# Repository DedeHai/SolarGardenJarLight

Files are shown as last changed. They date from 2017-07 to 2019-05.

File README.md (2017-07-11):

# Solar Garden Jar Light
A solar powered LED light controlled by an Arduino. It is designed to fit inside most glass jars lighting up your garden or back yard in beatuiful colors. 
The Arduino is connected to an accelerometer to switch the light on and off and to change the color by tilting it. It was designed with easy assembly in mind to be sold as a DIY kit at [Fablab Winti](www.fablabwinti.ch). The voltage regulator as well as the power LED are removed from the Arduino to make it low power consumption consuming only 120µA on average when switched off, making the 500mAh battery last up to half a year when kept in the dark. The solar cell voltage is used to detect low light conditions at dawn and the light does automatically switch on for a few hours if the battery is fully charged. The threshold levels can be adjusted easily in the software.

More information available at https://bashtelorofscience.wordpress.com/ 

License:
Software source code is GNU GPL V3 licensed
Hardware under Creative Commons 4.0 license: CC-BY-NC-SA



# Software
The PCB was designed in **eagle** version 7.5.0. The firmware project was created using **Arduino IDE**.

# Fotos
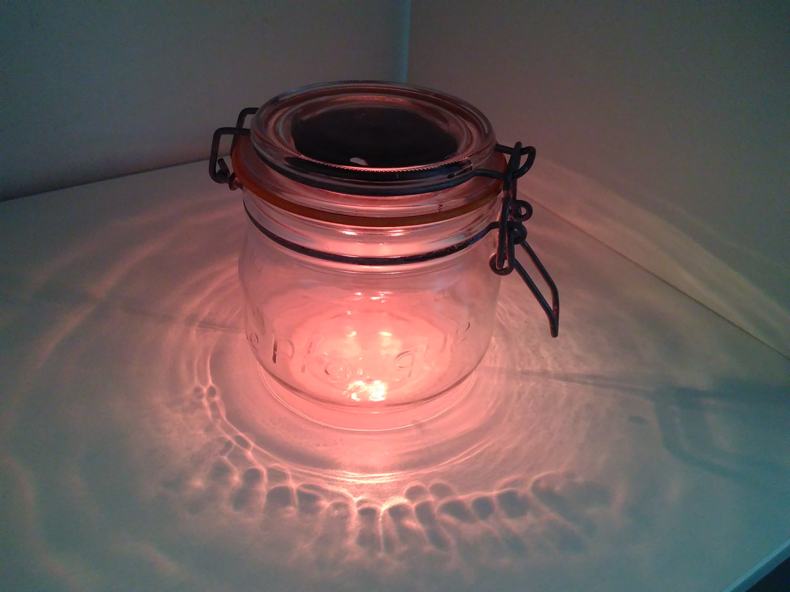
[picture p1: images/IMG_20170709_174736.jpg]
Finished Jar
 
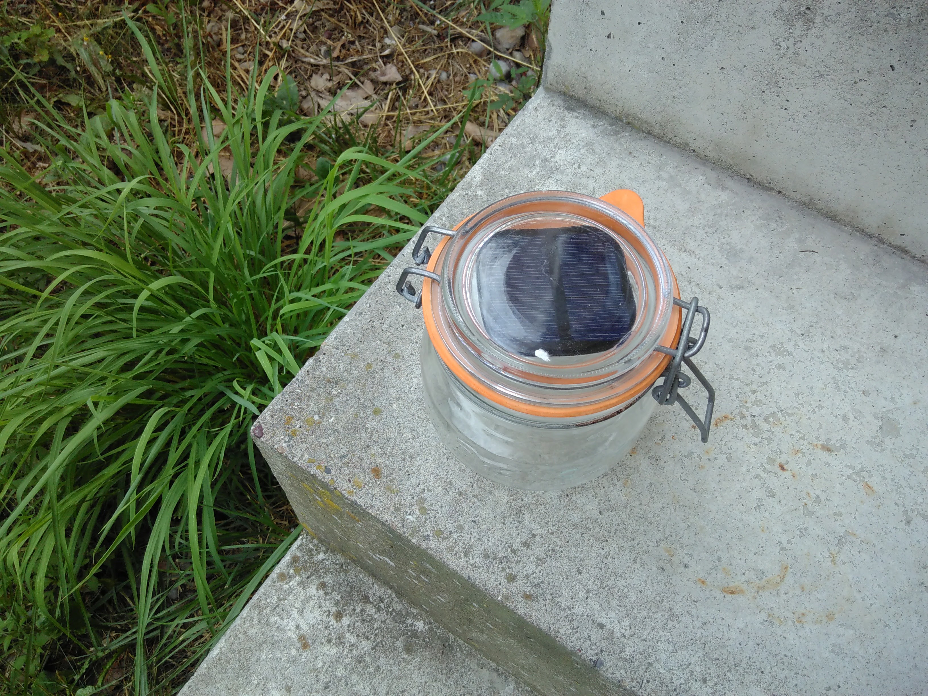
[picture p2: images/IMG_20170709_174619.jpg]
Outside
 
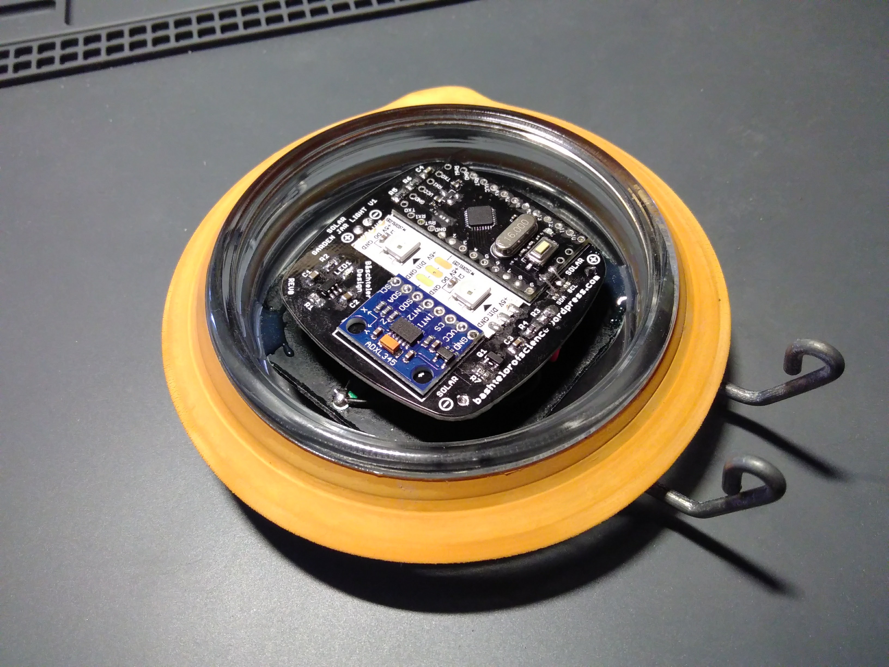
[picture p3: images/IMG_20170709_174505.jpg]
Assemblded Lid
 
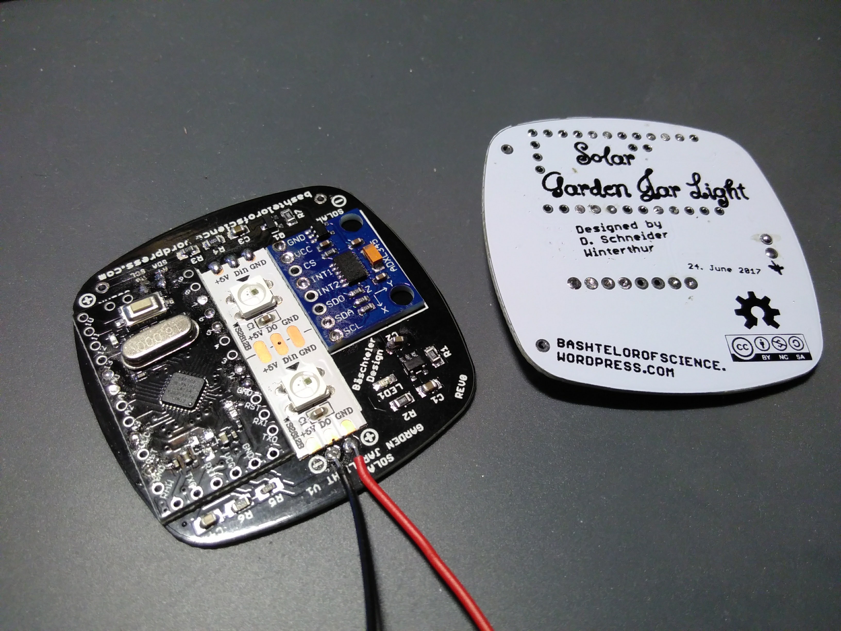
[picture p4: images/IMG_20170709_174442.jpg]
Assemblded PCB


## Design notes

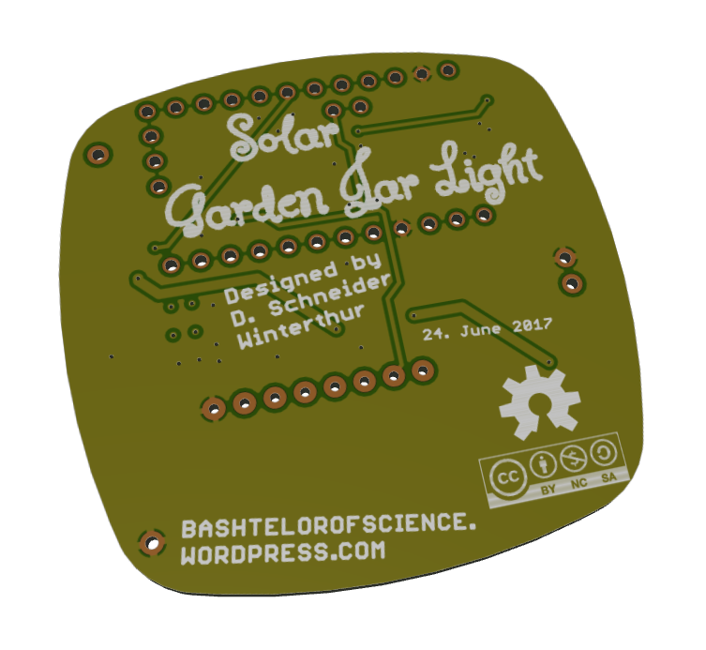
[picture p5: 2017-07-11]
Hardware/PCB_bottomview.PNG

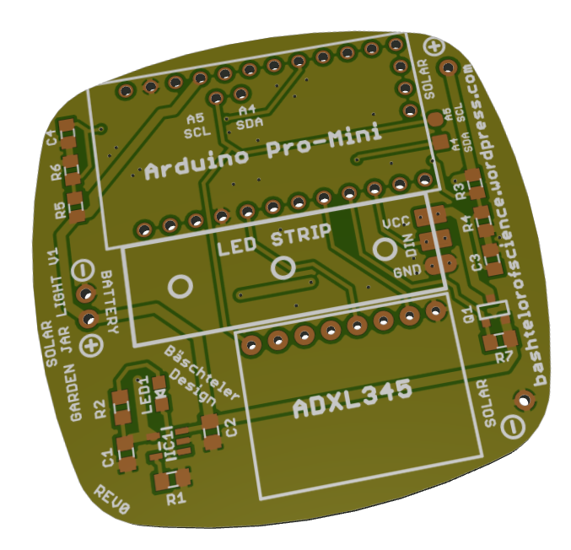
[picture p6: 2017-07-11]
Hardware/PCB_topview.PNG

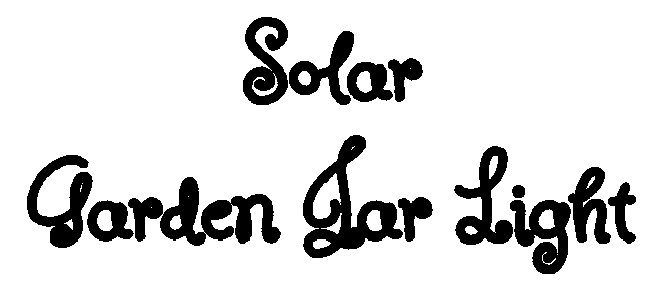
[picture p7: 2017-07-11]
Hardware/SolarGardenJarLight.bmp

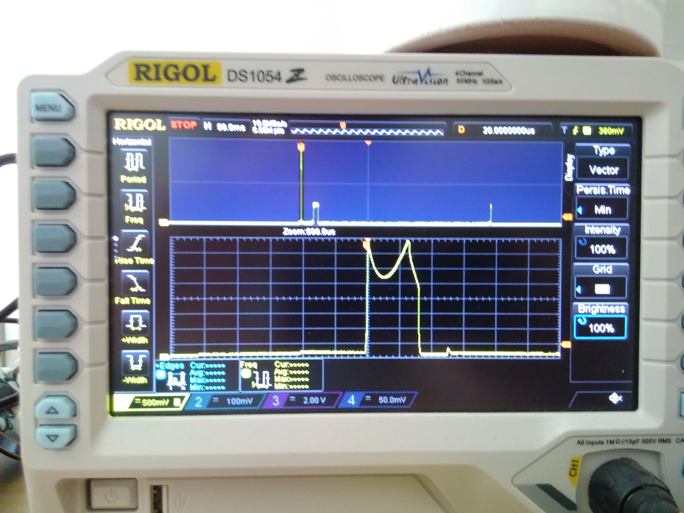
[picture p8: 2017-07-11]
images/initial spike 100x.jpg

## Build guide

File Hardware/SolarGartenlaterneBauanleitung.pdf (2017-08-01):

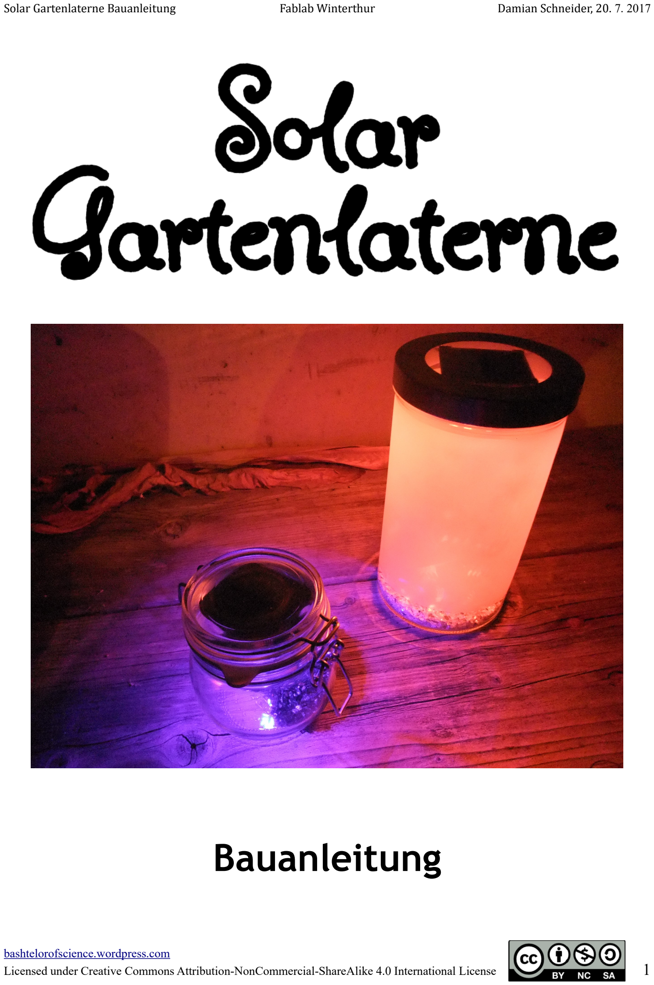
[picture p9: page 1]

Solar Gartenlaterne Bauanleitung | Fablab Winterthur | Damian Schneider, 20. 7. 2017

# Bauanleitung

bashtelorofscience.wordpress.com
Licensed under Creative Commons Attribution-NonCommercial-ShareAlike 4.0 International License | 1

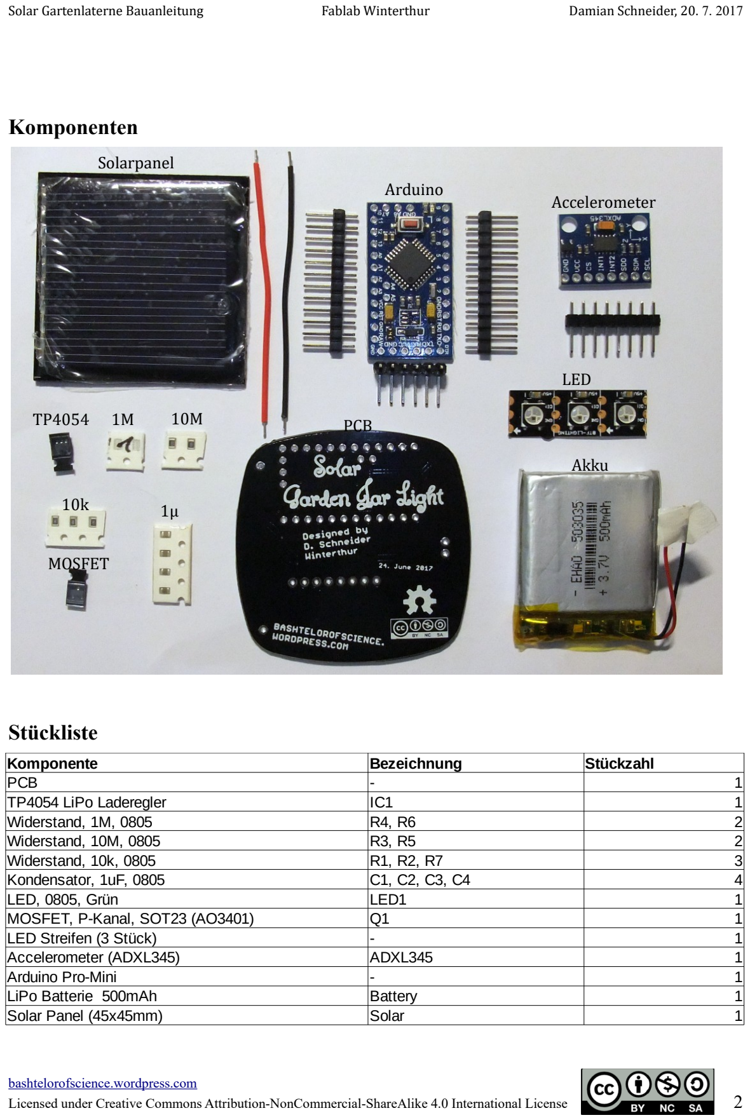
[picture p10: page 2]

Komponenten

Stückliste

bashtelorofscience.wordpress.com
Licensed under Creative Commons Attribution-NonCommercial-ShareAlike 4.0 International License | 2
1M | PCB

Solarpanel

MOSFET

Akku

10k | 1µ

TP4054

Arduino

LED

Accelerometer

10M

Komponente | Bezeichnung | Stückzahl
PCB | - | 1
TP4054 LiPo Laderegler | IC1 | 1
Widerstand, 1M, 0805 | R4, R6 | 2
Widerstand, 10M, 0805 | R3, R5 | 2
Widerstand, 10k, 0805 | R1, R2, R7 | 3
Kondensator, 1uF, 0805 | C1, C2, C3, C4 | 4
LED, 0805, Grün | LED1 | 1
MOSFET, P-Kanal, SOT23 (AO3401) | Q1 | 1
LED Streifen (3 Stück) | - | 1
Accelerometer (ADXL345) | ADXL345 | 1
Arduino Pro-Mini | - | 1
LiPo Batterie 500mAh | Battery | 1
Solar Panel (45x45mm) | Solar | 1

Bestückungsplan

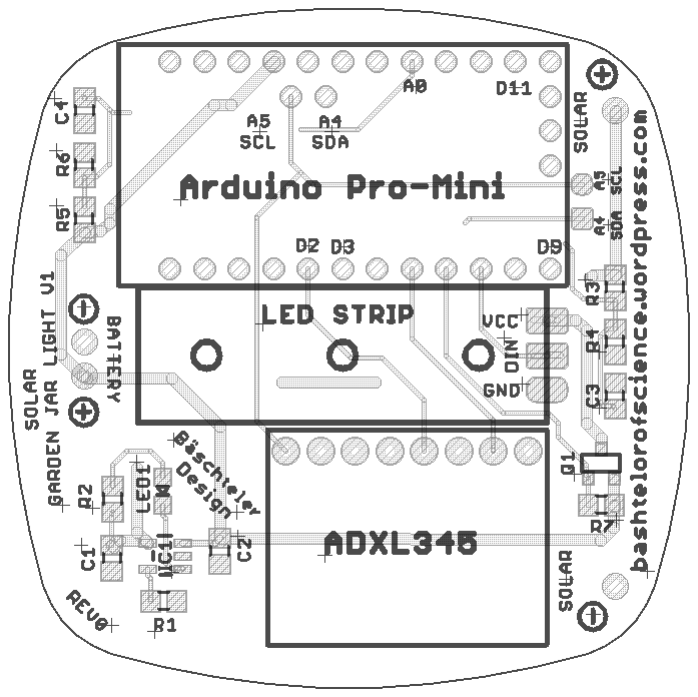
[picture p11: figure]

SMD Komponenten
Die SMD Komponenten gemäss obigem Bestückungsplane löten (Stückliste beachten). Wichtig ist dabei die Widerstände R3, R4, R5 und R6 nicht zu vertauschen. R3 und R5 sind 10M und R4 und R6 sind 1M. Beim IC1 ist besonders auf Kurzschlüsse zu achten und bei LED1 auf die korrekte Polarität.
Arduino
Das Arduino Pro-Mini ist bereits modifiziert: die Power-LED sowie der Linearregler wurde entfernt um den Stromverbrauch auf ein Minimum zu reduzieren.
Zuerst werden die Stiftleisten ins Arduino-Board eingelötet (kurze Stiftseite zum Arduino). Dabei die extra Pins A4 und A5 nicht vergessen (bei den blauen Boards, siehe Anmerkung unten)! Am einfachsten ist es, die Stiftleisten erst ins PCB der Solar-Gartenlaterne einzusetzen, das Arduino

bashtelorofscience.wordpress.com
Licensed under Creative Commons Attribution-NonCommercial-ShareAlike 4.0 International License | 3

daraufzusetzen und dann anzulöten. Damit sind die Pins sicher gut ausgerichtet (siehe Foto). Achtung: das Arduino nicht verkehrt herum einlöten, Ausrichtung siehe Bestückungsplan (Pins D2, D3, D9, D11, A0 beachten).

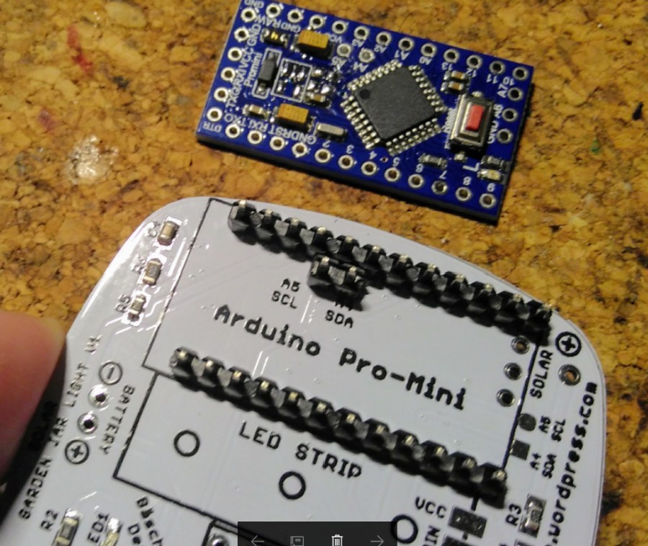
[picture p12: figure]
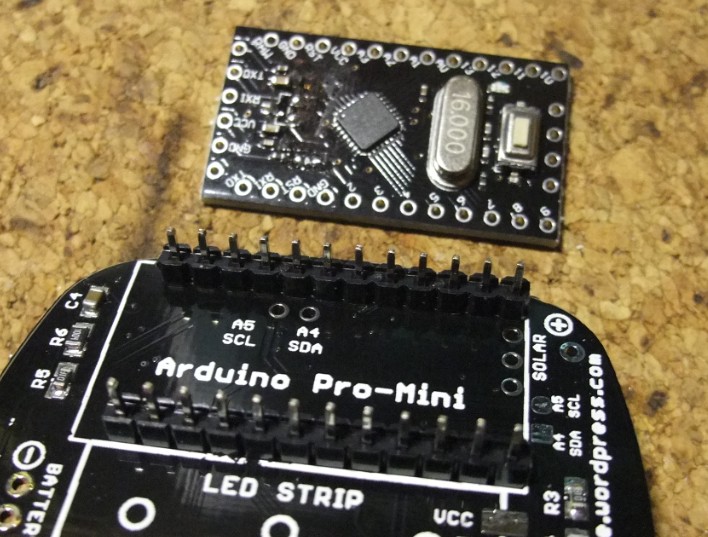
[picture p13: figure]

Blaue Version: A4 & A5 mit Stiftleiste verbinden, schwarze Version: siehe unten.

Anmerkung: es gibt diverse Versionen des Arduino Pro-Mini Klons. Bei einigen sind die Pins A4 und A5 an anderen Positionen. Bei diesen Versionen können diese beiden Pins mit Draht auf die Pads rechts vom Arduino gelötet werden. Hier ein Bild von drei gängigen Versionen:

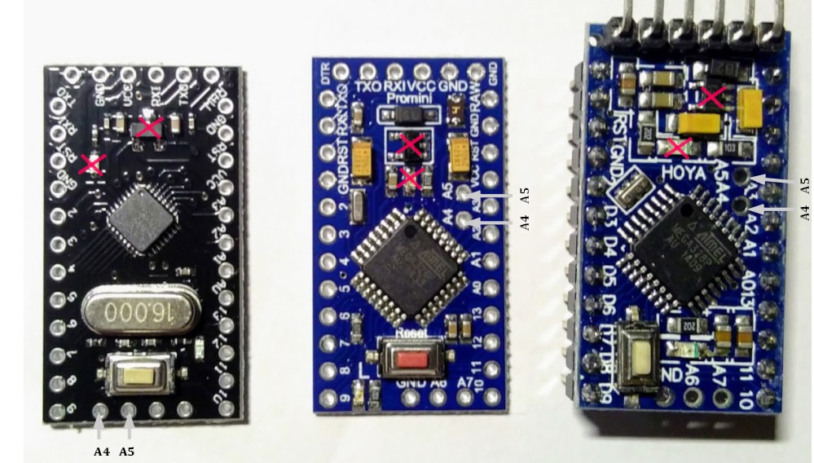
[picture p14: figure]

bashtelorofscience.wordpress.com
Licensed under Creative Commons Attribution-NonCommercial-ShareAlike 4.0 International License | 4

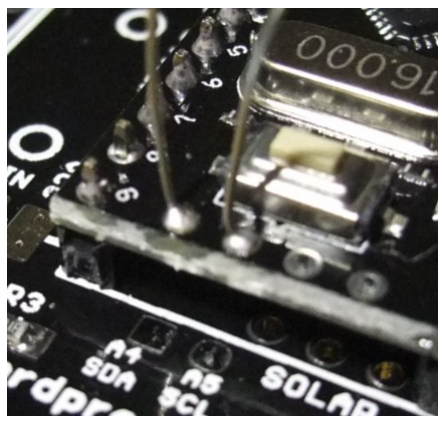
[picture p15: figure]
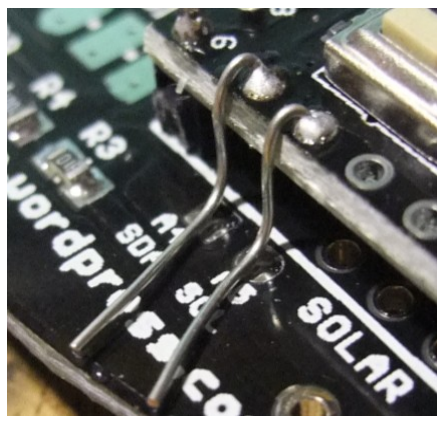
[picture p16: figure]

Verbinden der A4 und A5 Pins bei den schwarzen Arduinos

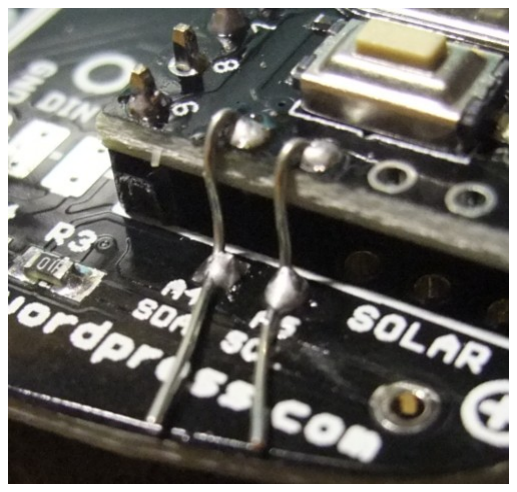
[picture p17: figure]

Nach dem Einlöten müssen die Pins unten am PCB abgeknipst werden ums später die Batterie ankleben zu können.
Accelerometer
Es ist wichtig, dass das Accelerometer-Modul ganz flach aufliegt. Die Stiftleiste kann von unten in die Löcher eingesteckt werden und das Accelerometer dann von oben (mit der Platine bündig). Von oben her verlöten, die Pins unten mit dem Seitenschneider abzwicken und auch unten löten.
LED
Die Schutzfolie unten am LED-Streifen entfernen und die LEDs in korrekter Ausrichtung aufkleben. Unbedingt die Pfeilrichtung beachten: falsch eingelötete LEDs werden beim einschalten zerstört! Beim anlöten genügend Zinn verwenden und lange genug heizen, so dass kugelförmige Lötstellen entstehen (siehe Foto). Nach dem löten mit dem Multimeter auf Kurzschlüsse prüfen.

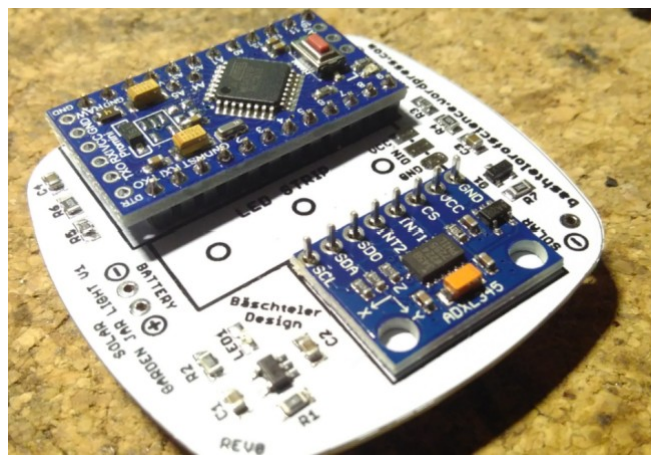
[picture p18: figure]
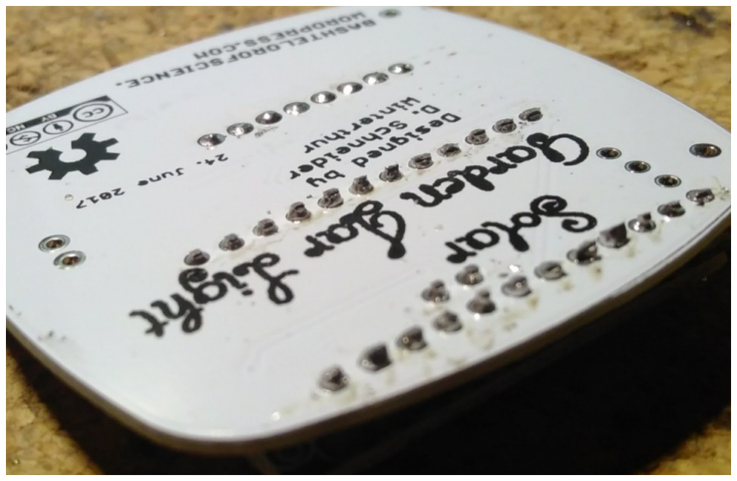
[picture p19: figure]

bashtelorofscience.wordpress.com

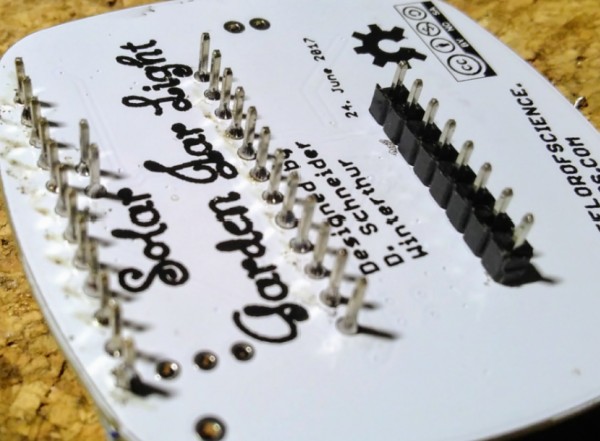
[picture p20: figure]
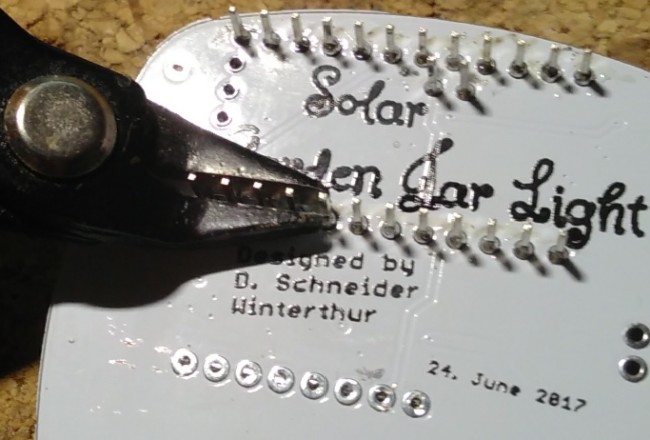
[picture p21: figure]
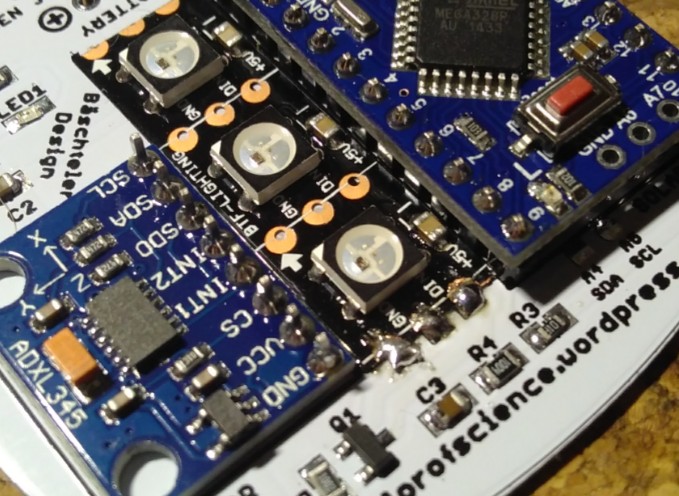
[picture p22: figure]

Licensed under Creative Commons Attribution-NonCommercial-ShareAlike 4.0 International License | 5

Solarpanel
Das Solarpanel in der richtigen Polarität an den beiden mit ‚SOLAR‘ bezeichneten Pads einlöten. Akku
Vorsicht beim Umgang mit dem Akku: Lithium Akkus haben einen sehr geringen innen widerstand und liefern dementsprechend hohe Ströme beim kurzschliessen (10A und mehr). Die Leistung genügt um Kabel zu schmelzen oder die Platine zu zerstören. Zum sicheren einlöten zuerst beide Lötaugen mit Lötzinn füllen. Dann nur den Schutz am schwarzen Kabel entfernen und dieses am Negativen Pad (‚BATTERY‘) einlöten. Nun den Schutz am roten Kabel entfernen und am positiven Pad einlöten und darauf achten, mit diesem Kabelende keine leitenden Stellen auf der Platine zu berühren. Die Elektronik ist nun funktionstüchtig. Die LEDs können durch wiederholtes Tippen auf die Platine eingeschaltet werden. Das Licht wird automatisch wieder ausgeschaltet, wenn die LEDs nach oben zeigen. Wird die Platine umgedreht, bleiben die LEDs an.

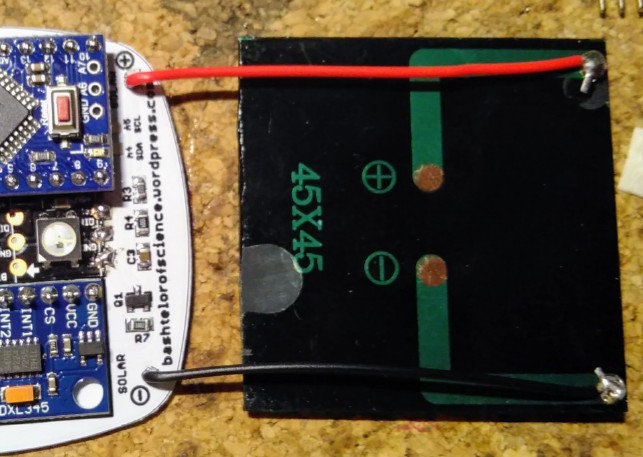
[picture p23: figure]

Verkleben

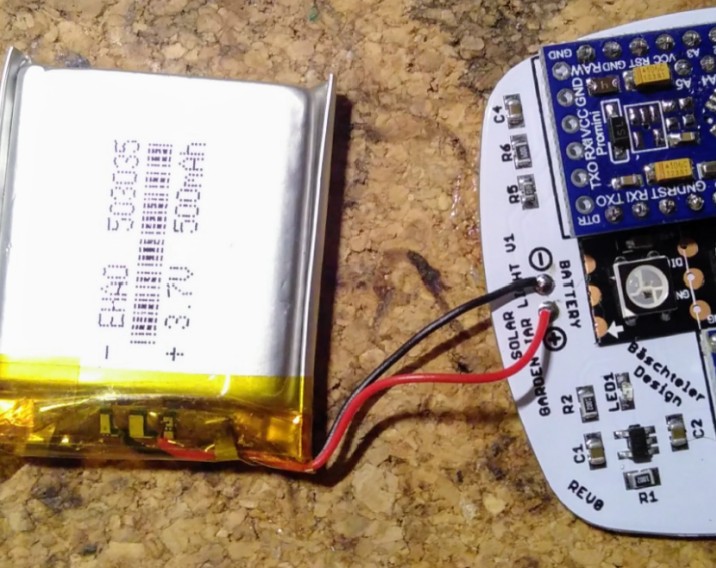
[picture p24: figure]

Bevor der Akku auf die Platine geklebt wird unbedingt die abgeknippsten Pins mit dünnen Klebebandstreifen isolieren, damit die Akkuhülle nicht angestochen wird.
Der Akku kann mit Cementit oder auch mit Bausilikon angeklebt werden. Kein Weissleim verwenden, der ist leitend! Auf den Akku wird dann die Solarzelle geklebt. Danach wird das Paket mit Klebeband fixiert. Es ist darauf zu achten, dass die Platine und die Solarzelle möglichst parallel zueinander sind. Man kann auch doppelseitiges Klebeband verwenden, das hält aber nicht ewig.

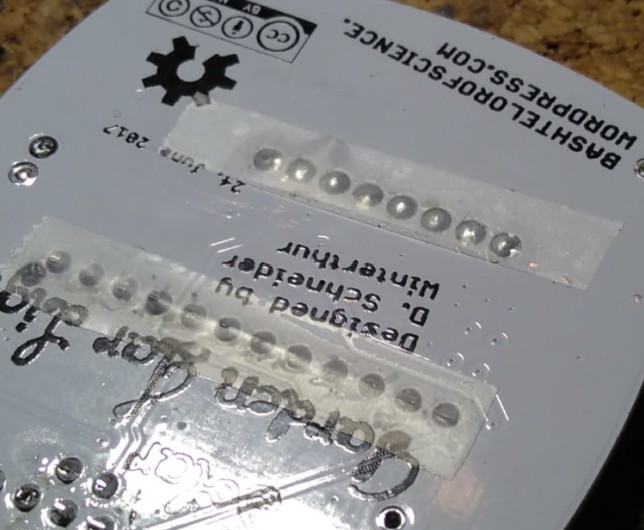
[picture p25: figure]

bashtelorofscience.wordpress.com

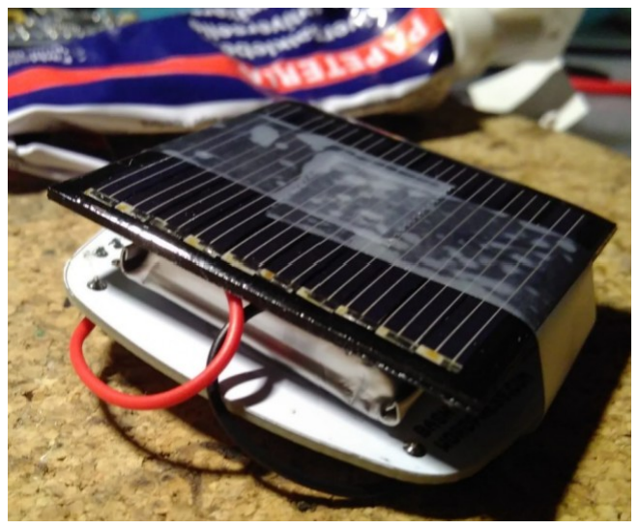
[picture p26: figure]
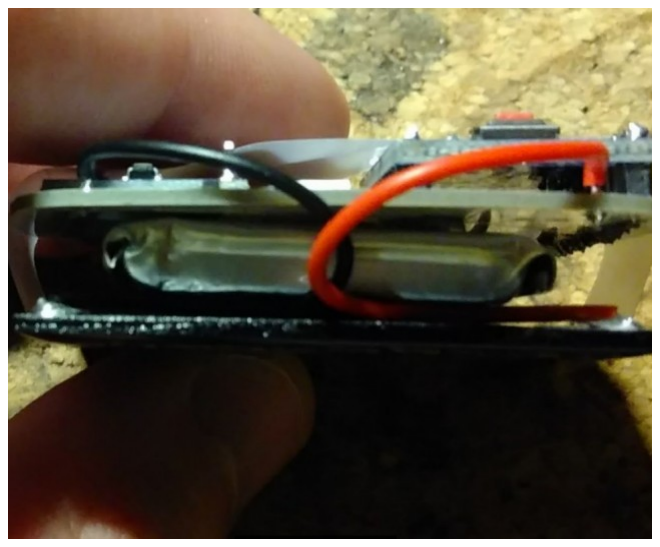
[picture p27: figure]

Licensed under Creative Commons Attribution-NonCommercial-ShareAlike 4.0 International License | 6

Die Laterne Bauen
Die Elektronik kann nun in einen beliebigen Behälter mit transparentem Deckel eingebaut werden. Einmachgläser bieten sich besonders an, da sie Nacht dem Verschliessen Wasserdicht sind. Die Solarzelle wurde so gewählt, dass sie ohne die Ecken abzuschleifen in ein Einmachglas von Migros, Coop oder Ikea passen. Es ist wichtig, dass das Glas absolut wasserdicht ist! Die unten abgebildeten Dosendeckel von Ikea haben ein Loch und sind somit nur an geschützten Stellen verwendbar. Nach einem Test kann die Elektronik auch mit Kunstharz vergossen werden um sie vor Feuchtigkeit zu schützen.
Um die Solarzelle zu kleben entfernt man am besten den Deckel vom Glas, legt es flach auf den Tisch und gibt etwas transparenten Bausilikon hinein, der haftet besonders gut auf Glas und greift die Solarzelle nicht an. Jetzt wird die Elektronik mit der Solarzelle zum Glas hin eingesetzt und festgedrückt. Das Silikon braucht ca. 12h zum trocknen. Der transparente Prix Garantie Silikon aus dem Coop Bau und Hobby eignet sich gut und trocknet schnell.

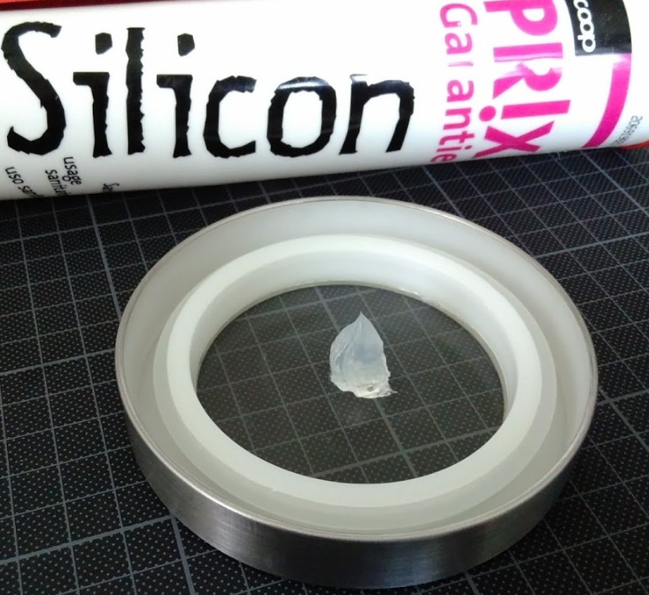
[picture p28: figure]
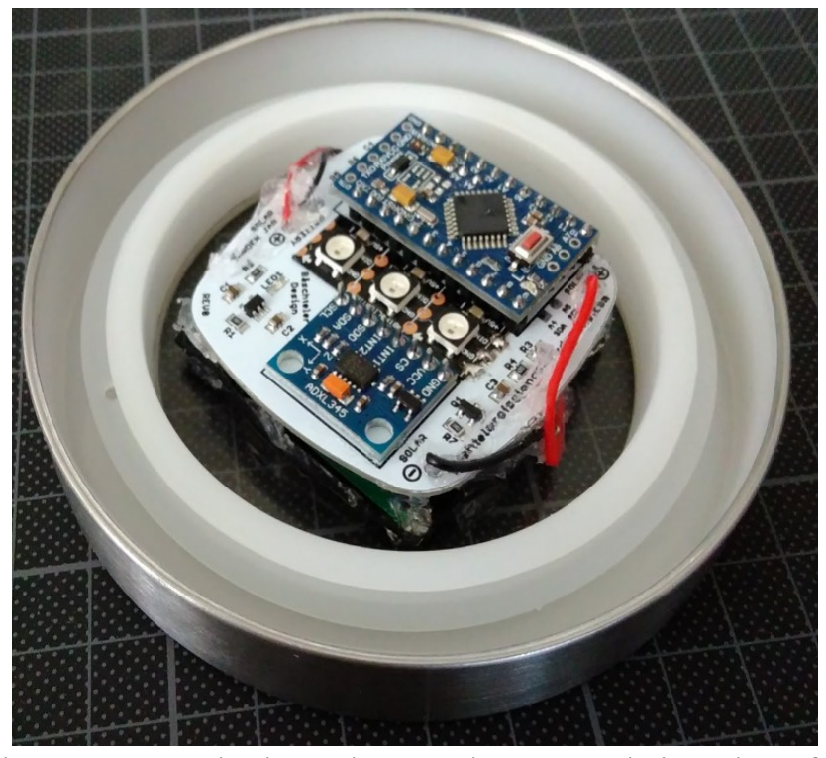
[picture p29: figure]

Die fertige Laterne kann zur Dekoration auch mit Steinen, Muscheln oder anderem Kleinod gefüllt werden.
Betriebsanleitung
Einschalten: die Laterne schaltet bei Dämmerung automatisch ein. Man kann die Laterne auch schütteln oder mit dem Finger wiederholt drauf-klopfen um sie einzuschalten.
Ausschalten: die LEDs schalten aus, wenn die Laterne kopfüber gedreht wird (Vorsicht bei gefüllten Laternen) so dass die Solarzelle Richtung Boden zeigt.
Farbe einstellen: die Farbe wird durch kippen der Laterne verstellt, die Farbe bleibt sobald die Laterne wieder flach gehalten wird. Durch Einmaltippen oben auf die Laterne schaltet man um zwischen: Farbe ändern, Helligkeit ändern, Farbsättigung ändern.
Kerzenmodus: durch Doppeltippen oben auf die Laterne wird der flackernde Kerzenmodus aktiviert. Durch nochmaliges Doppeltippen wird der Modus deaktiviert.
Zurücksetzen: durch Doppeltippen im Kerzenmodus werden Helligkeit und Sättigung auf den Maximalwert zurück gesetzt.

bashtelorofscience.wordpress.com
Licensed under Creative Commons Attribution-NonCommercial-ShareAlike 4.0 International License | 7

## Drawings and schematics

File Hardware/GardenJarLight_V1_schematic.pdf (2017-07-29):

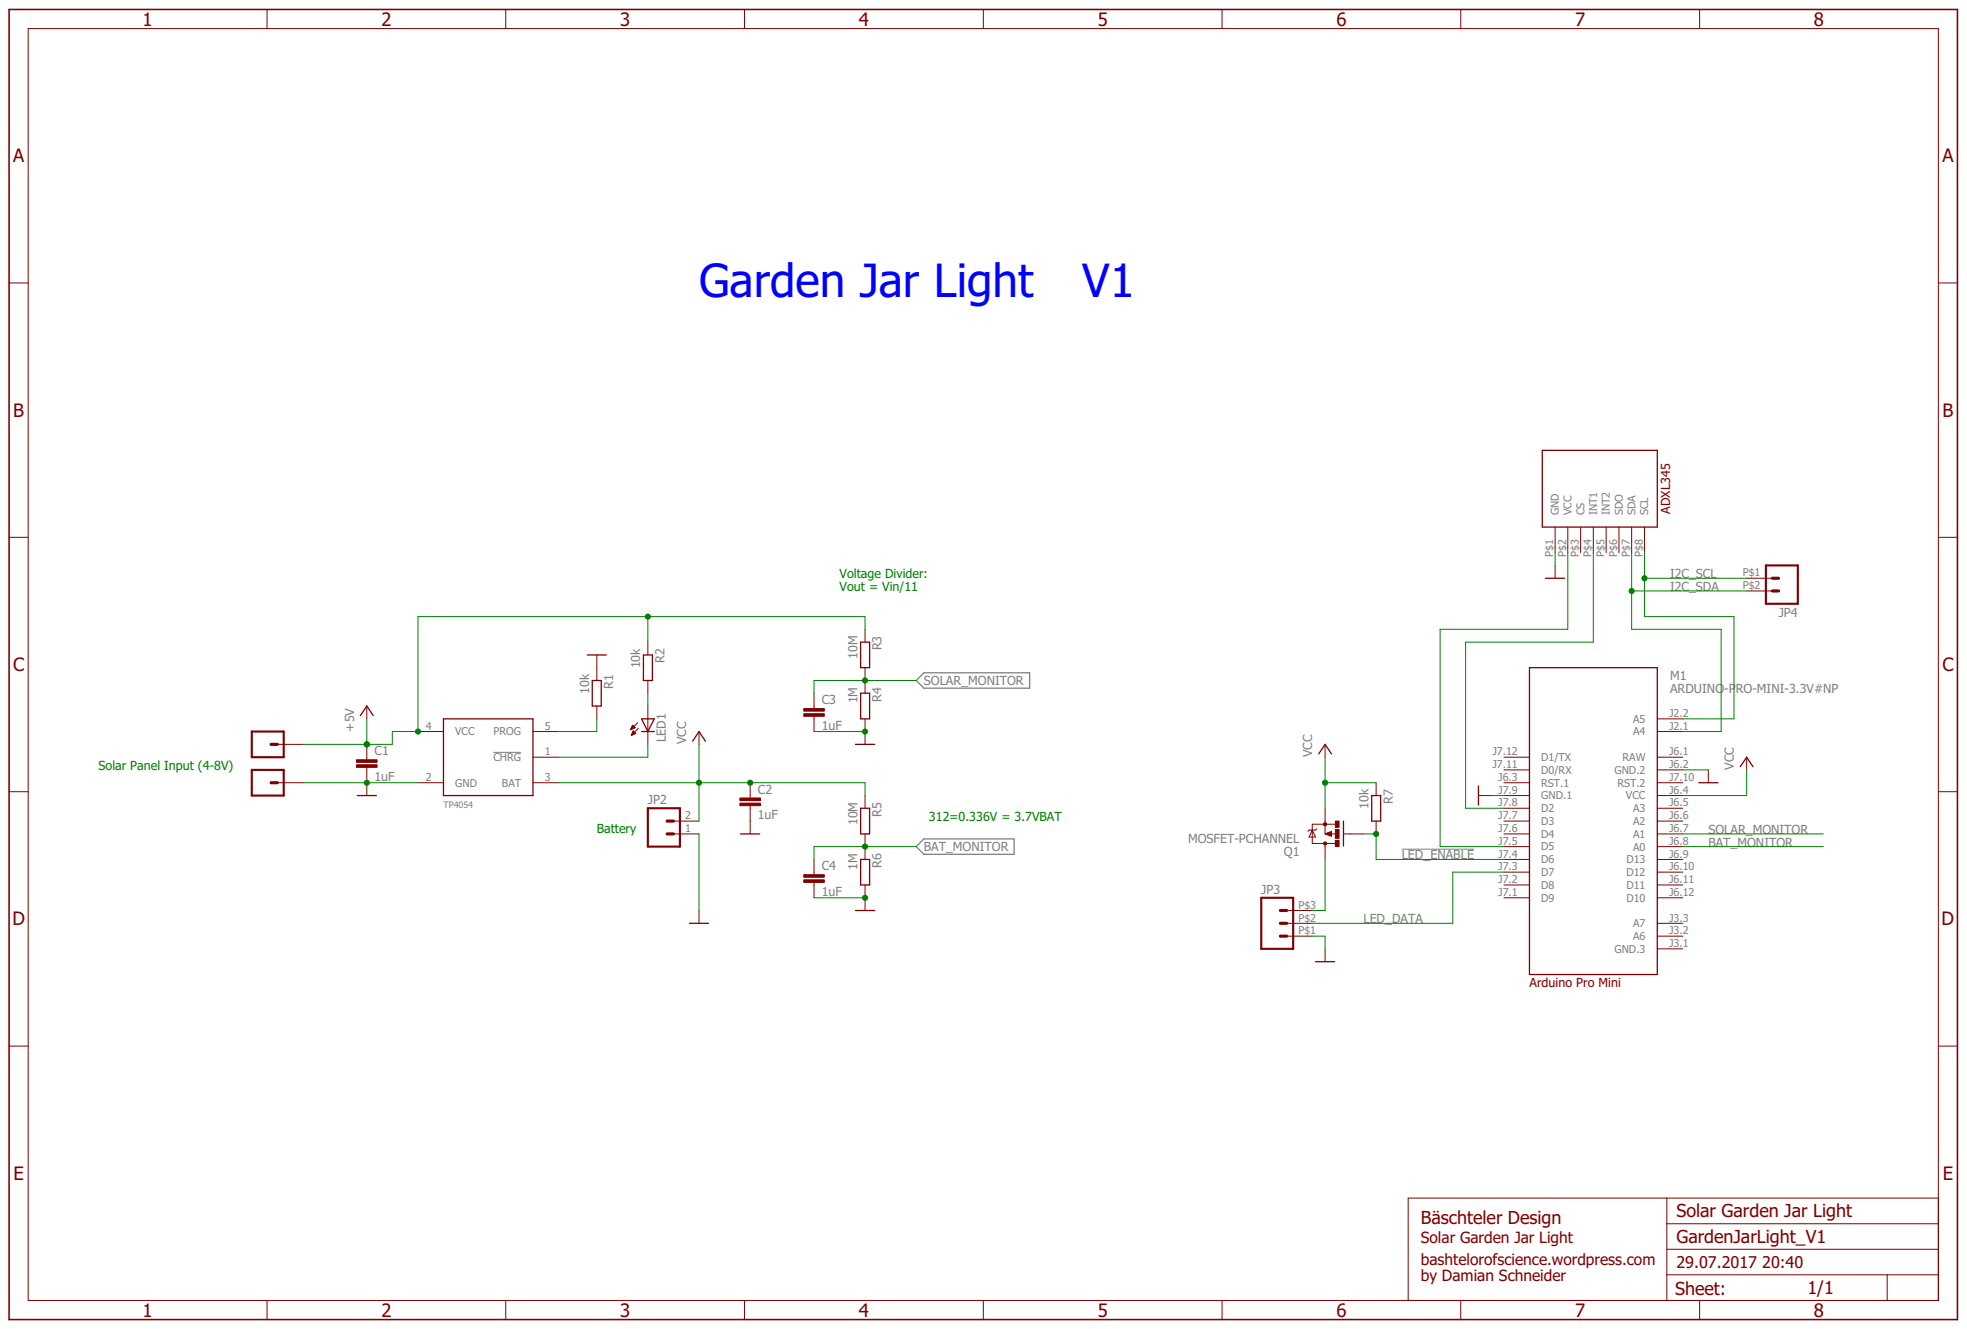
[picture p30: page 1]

Voltage Divider: Vout = Vin/11

ARDUINO-PRO-MINI-3.3V#NP

Bäschteler Design
by Damian Schneider Solar Garden Jar Light
bashtelorofscience.wordpress.com

Solar Garden Jar Light

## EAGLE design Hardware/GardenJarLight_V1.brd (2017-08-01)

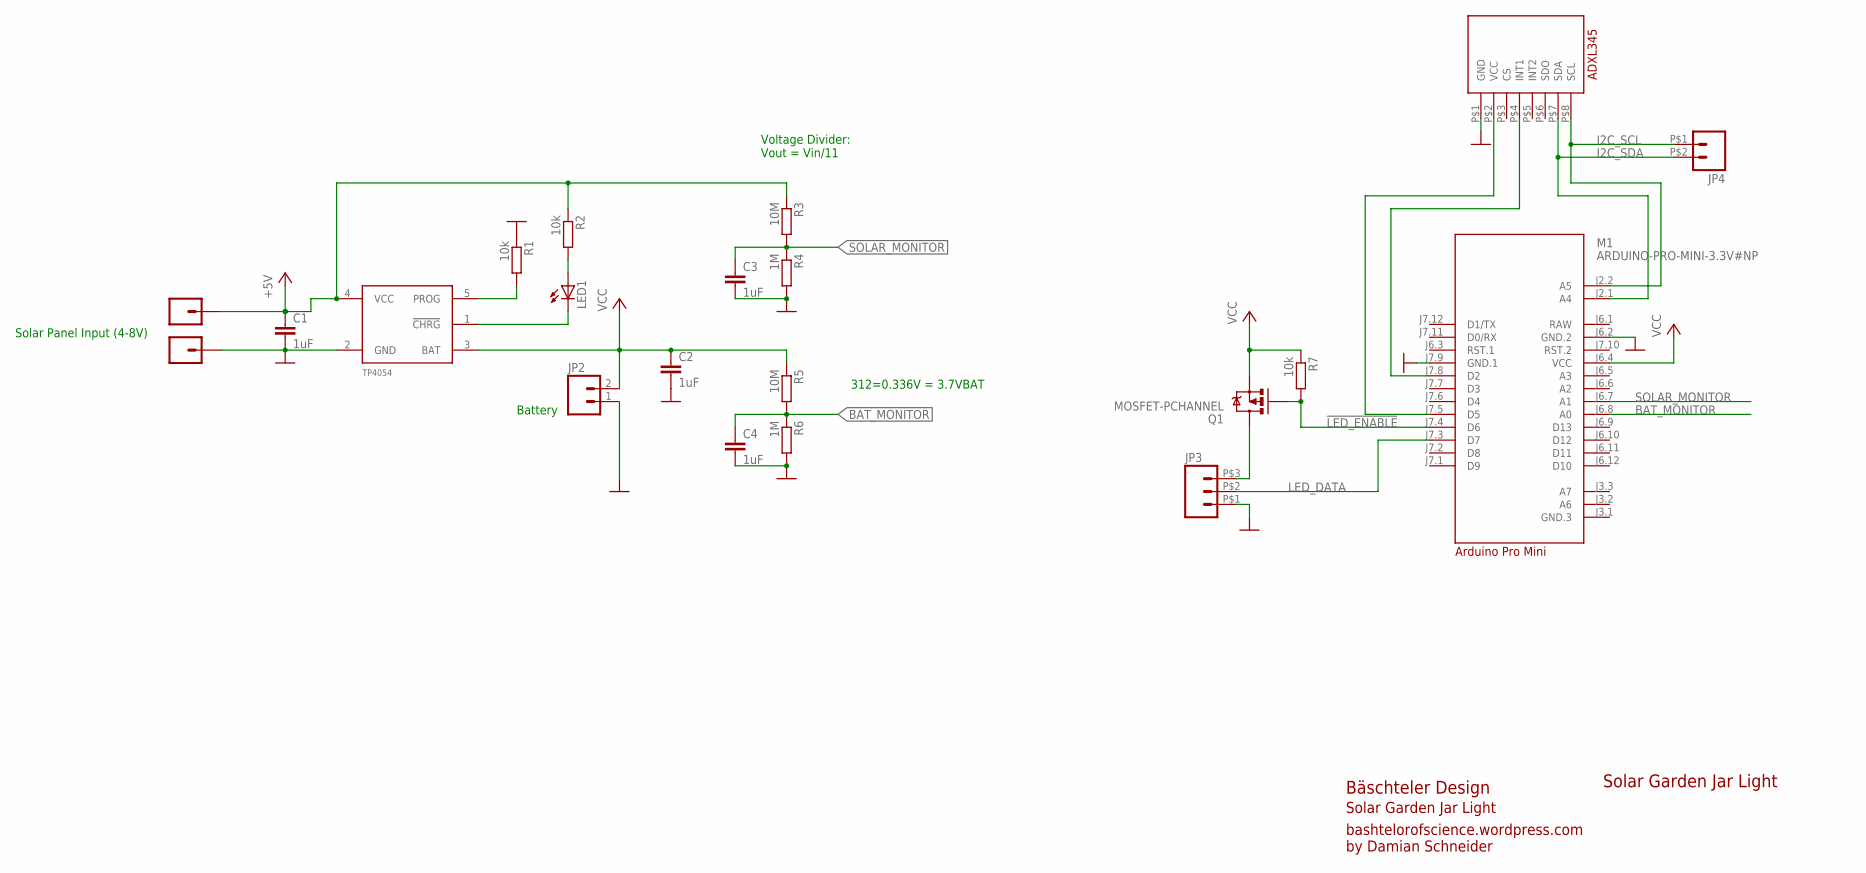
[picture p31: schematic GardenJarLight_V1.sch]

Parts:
C1, C2, C3, C4: 1uF; C0805
IC1: TP4054_LIPO_CHARGER; SOT23-5
JP1, JP5: M01PTH; 1X01
JP2: M021X02_NO_SILK; 1X02_NO_SILK
JP3: M03SMD_LONG; SMD_HEADER_3P_LONG
JP4: M02; SMD_HEADER_2P
LED1: LEDCHIPLED_0805; CHIPLED_0805
M1: ARDUINO-PRO-MINI-3.3V#NP; ARDUINO-PRO-MINI#NP
Q1: MOSFET-PCHANNEL; SOT23-3
R1, R2, R7: 10k; R0805
R3, R5: 10M; R0805
R4, R6: 1M; R0805
U$1: ADXL345

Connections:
!LED_ENABLE: M1.J7.4 (D6), Q1.1 (G), R7.2
+5V: C1.1, IC1.4 (VCC), JP1.1, R2.1, R3.1
BAT_MONITOR: C4.1, M1.J6.8 (A0), R5.2, R6.1
GND: C1.2, C2.2, C3.2, C4.2, IC1.2 (GND), JP2.1, JP3.P$1 (1), JP5.1, M1.J6.2 (GND.2), M1.J7.9 (GND.1), R1.1, R4.2, R6.2, U$1.P$1 (GND)
I2C_SCL: JP4.P$1 (1), M1.J2.2 (A5), U$1.P$8 (SCL)
I2C_SDA: JP4.P$2 (2), M1.J2.1 (A4), U$1.P$7 (SDA)
LED_DATA: JP3.P$2 (2), M1.J7.3 (D7)
unnamed: JP3.P$3 (3), Q1.3 (D)
unnamed: IC1.1 (!CHRG), LED1.C
unnamed: IC1.5 (PROG), R1.2
unnamed: M1.J7.8 (D2), U$1.P$4 (INT1)
unnamed: M1.J7.5 (D5), U$1.P$2 (VCC)
unnamed: LED1.A, R2.2
RAW: M1.J6.1 (RAW)
SOLAR_MONITOR: C3.1, M1.J6.7 (A1), R3.2, R4.1
VCC: C2.1, IC1.3 (BAT), JP2.2, M1.J6.4 (VCC), Q1.2 (S), R5.1, R7.1

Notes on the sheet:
Battery
Solar Panel Input (4-8V)
312=0.336V = 3.7VBAT
Voltage Divider: Vout = Vin/11
Bäschteler Design
bashtelorofscience.wordpress.com by Damian Schneider
Solar Garden Jar Light
Arduino Pro Mini

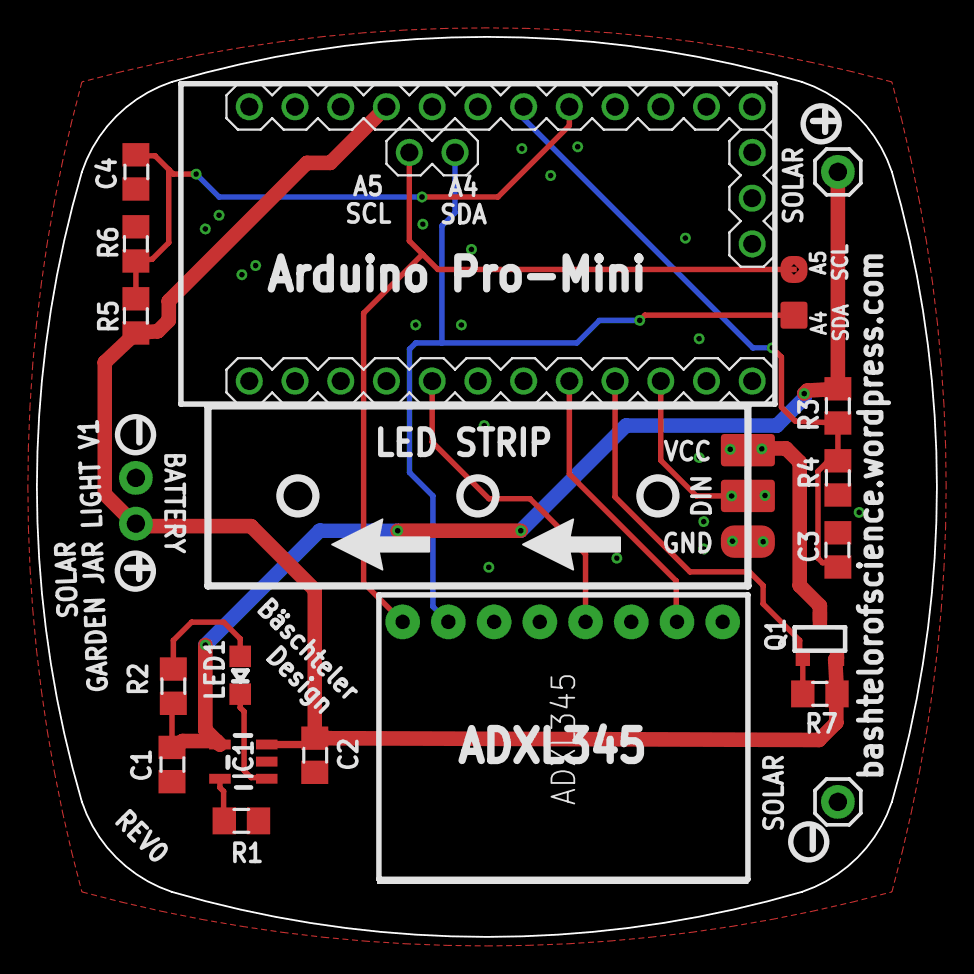
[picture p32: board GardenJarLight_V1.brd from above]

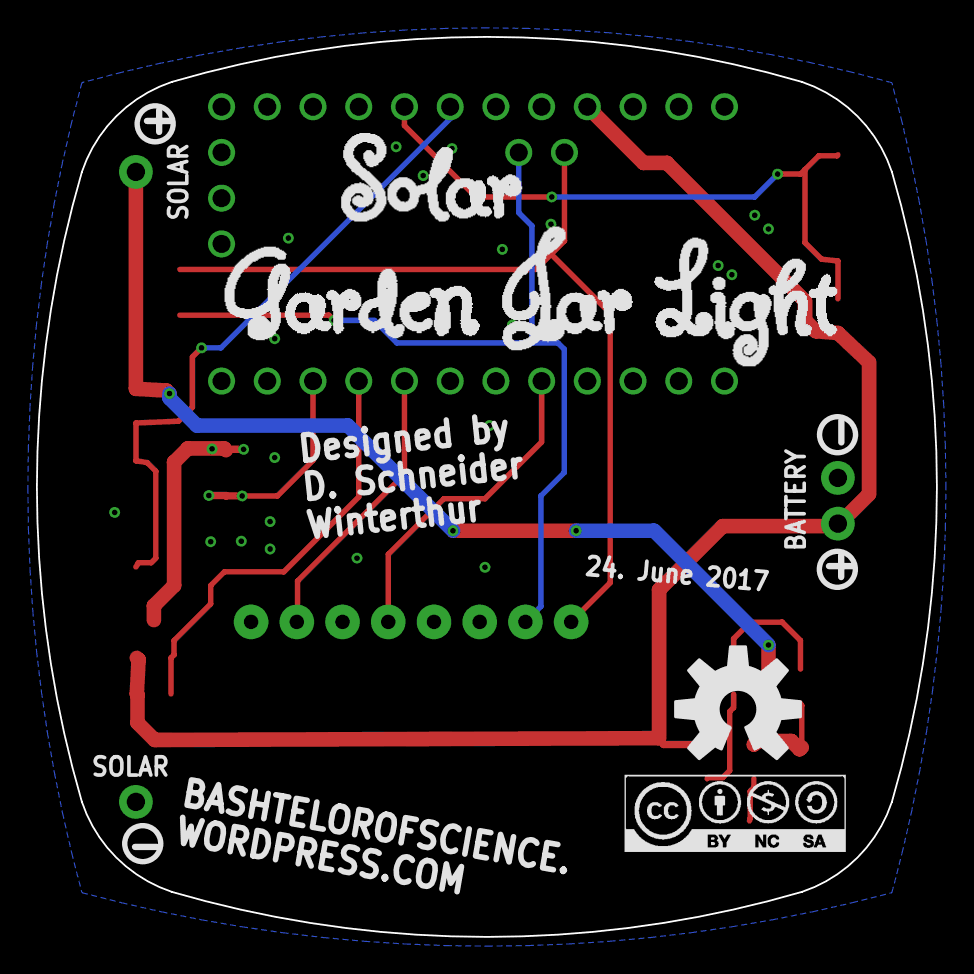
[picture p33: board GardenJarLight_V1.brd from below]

Board: 2 copper layers, 50.0 x 50.0 mm, 23 parts (2 on the bottom side), 15 nets.

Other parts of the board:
U$4: CC-BY-NC-SA
U$33: OSHW-LOGO-L

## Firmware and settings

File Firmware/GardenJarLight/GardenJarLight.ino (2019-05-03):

/*
  SOLAR GARDEN JAR LIGHT

  by Damian Schneider
 *************************

   Copyright (c) Damian Schneider 2017

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
   You should have received a copy of the GNU General Public License along with
   this program. If not, see <http://www.gnu.org/licenses/>.
*/

/*
  Notes & Calculations:

  This code was tested and working using Arduino 1.6.8 and Arduino 1.8.5
  It works on Arduinos using ATmega328 and ATmega168P (Arduino Pro-Mini)

  IMPORTANT: to avoid constant reboots upon an I2C error (which sometimes can happen) replace the twi.c file in your arduino folder 
  (YOURARDUINOLOCATION\hardware\arduino\avr\libraries\Wire\src\utility) with the twi.c file in the zip file provided.
  it contains my bugfix to not get the arduino stuck in an infinite loop when the accelerometer does not respond

  solar cell power:
  the solar cell delivers around 3-5mA when charging in the shade or light overcast. In full sunlight, it is probably more like 50mA.
  when charging for about 10 hours on an average of 5mA this equals only 50mAh which powers the LEDs on reduced brightness for about two hours (assuming 25mA current). todo: test this some more

  Note: need to mention that only Atmega 328P and ATmega 168PA work with this code (tested, all processors with micro power work but may need an adjusted low power function)

  Power consumption:
  -the ATMEGA368P boards and ATMEGA168PA boards use about 5uA  during low power sleep
  -the finished circuit consumes 8.5uA during sleep, 8.5mA when running (without LED on) and about 0.25mA with the accelerometer running and the MCU in low power sleep
    the run times during wakeup are: 7.6+0.3ms in run mode 820us in power up mode (charging the cap of the accelerometer at about 17mA) and 250ms in low power with the accelerometer on
    the wake period is followed by 1000ms of low power sleep at 8.5uA
    that totals in approximately 9.5ms*8.5mA+250ms*0.25mA+1000*0.0085mA = 152mAms resulting in an average current of 120uA

  At the average current of 120uA a 500mAh battery will last almost half a year if not re-charged (consumption of 2.88mAh per day)
  A solar panel delivering just 5mA for a few hours a day is enough to slowly charge the battery!
  Small 5.5V solar panels deliver a lot more power than this if placed in sunlight. Even on an overcast sky the 5mA are easily reached.


  todo:
  -could add a battery charge monitoring function that checks the voltage difference in intervals of 1h and if it never rises goes into an ultra low power mode, saving the battery if there is no power source available (i.e. it is not placed somewhere bright)

*/

#include <Wire.h>
#include <FastLED.h>

#include <SparkFun_ADXL345.h>         // SparkFun ADXL345 Library
//low power stuff (cannot use low power library as it does not support ATMEGA168P devices)
#include <avr/sleep.h>
#include <avr/wdt.h>
#include <avr/power.h>
#include <avr/interrupt.h>


ADXL345 adxl = ADXL345();

//#define SERIALDEBUG 1 //serial output debugging data if defined
#define RANDOMCOLORATWAKEUP 1 //if defined, a random color is assigned at auto-wakeup

#define AUTOPOWEROFFTIME 200 //time in minutes after which the light turns off automatically 

#define LED_PIN     7 //LED data pin
#define LEDPWR_PIN  6 //LED power pin (inverting, low means on)
#define ACC_PIN     5 //power pin for accelerometer
#define BATTERYVOLTAGE_PIN A0
#define SOLARVOLTAGE_PIN A1

#define COLOR_ORDER GRB
#define CHIPSET     WS2812B
#define NUM_LEDS    3 //number of leds connected-

#define BRIGHTNESS  180 //manual-on brightness setting
#define AUTOMAXBRIGHTNESS  200 //auto-on maximum brightness setting
#define AUTOMINBRIGHTNESS  20 //auto-on minimum brightness setting


#define STATE_CHANGECOLOR     0
#define STATE_CHANGEBRIGHTNES     1
#define STATE_CHANGESATURATION     2

//LED modes:
#define STATICMODE 0
#define CANDLEMODE 1 //if a mode is added, change LASTMODE to the new mode (used for mode counting)
#define LASTMODE CANDLEMODE

//global variables
uint8_t led_state;
bool running = false; //low power mode if not running, set to true once ADXL tap interrupt is detected, led will then be switched on
bool gravitycolor_active = true; //if active, tilting changes the color. is set inactive after 30s of idling
bool wakeup = false;
bool autoOn = false; //set to true once the light is switched on automatically, set back to false once it is no more dark outside (at dusk), also disabled on manual on
byte itsDarkOutside = 0; //counts up if darkness is detected (by checking solar panel voltage), down if not
bool tap_detect = false;
bool doubletap_detect = false;

bool voltageLow = false;
long ontimeCounter = 0; //counter to track on-time
unsigned int minutecounter = 0; //approximately counts the on-time minutes (derived from ontimeCounter)
int lowPowerCheckCounter = 0; //counter to check voltages when not running (for auto-on mode), incremented after low power sleep (~every 2 seconds)
byte switchoffcounter = 0; //switch off if turned upside down for more than one second

byte ledmode = 0; //start off with the first mode

//LED HSV color
CHSV ledcolor_hsv; //LED hsv color
CRGB leds[NUM_LEDS]; //data array for the RGB colors (these are sent out to the leds)




void setup() {

  MCUSR = 0; //reset MCU status reset register (must be cleared to disable watchdog reset, this may also be called in arduino core, did not check)
  WDTCSR |= (1 << WDCE); //watchdog change enable, must be set to be able to clear WDE bit
  WDTCSR &= ~(1 << WDE); //disable watchdog resetting the system (must be cleared after WDRF is cleared in MCUSR)
  wdt_disable(); //disable the watchdog timer (in case the watchdog interrupt did reset the system)

#ifdef SERIALDEBUG
  Serial.begin(115200);
  Serial.println("Garden Jar Light V1.0");
  delay(10);
#endif

  //blink the LED on the arduino on bootup (to check if it is constantly rebooting, hunting a bug where the light does not react to shaking until reset is pressed)
  pinMode(13, OUTPUT);
  digitalWrite(13, HIGH);
  delay(200);
  digitalWrite(13, LOW);
  pinMode(13, INPUT);

  pinMode(LEDPWR_PIN, INPUT);
  digitalWrite(LEDPWR_PIN, HIGH); //LEDs OFF  //todo: with a pullup, make this an input and only make it an output when running
  ledcolor_hsv.h = 18;
  ledcolor_hsv.s = 255;
  ledcolor_hsv.v = 255;
  analogReference(INTERNAL);
  FastLED.addLeds<CHIPSET, LED_PIN, COLOR_ORDER>(leds, NUM_LEDS).setCorrection( TypicalLEDStrip );
  FastLED.setBrightness(BRIGHTNESS);
  randomSeed(getBatteryVoltage()+getBatteryVoltage()+getBatteryVoltage());
  powerDown(WDTO_2S); //wait 2 seconds in low power mode in case the ADXL345 is broken and the system reboots due to watchdog timeout this will save a lot of power, preventing the battery to die

}

void loop()
{
  static uint8_t delaycounter = 0; //counter for delayed tilting color-update

  if (running)
  {
    wdt_reset(); //kick the watchdog timer signalling the main loop is still running
    ontimeCounter++; //increment the on-time, main loop runs at 44Hz in normal mode and at 300Hz in candle mode

    // Accelerometer Readings
    int x, y, z;
    adxl.readAccel(&x, &y, &z);         // Read the accelerometer values and store them in variables declared above x,y,z


    if (z > 50) //jar is upside down (electronics facing upwards)
    {
      switchoffcounter++;
    }
    else
    {
      switchoffcounter = 0;
    }

    // Output Results to Serial
#ifdef SERIALDEBUG

    Serial.print(x);
    Serial.print(", ");
    Serial.print(y);
    Serial.print(", ");
    Serial.println(z);
#endif

    ADXL_ISR(); //check accelerometer interrupts by polling

    if (tap_detect)
    {
      tap_detect = false;
      led_state++;
      if (led_state > STATE_CHANGESATURATION) led_state = STATE_CHANGECOLOR;
    }

    if (doubletap_detect)
    {
      doubletap_detect = false;
      tap_detect = false;
      led_state = STATE_CHANGECOLOR; //go to color changing mode upon double tap
      ledmode++;
      if (ledmode > LASTMODE)
      {
        ledmode = 0;
        //also set high brightness and full saturation
        ledcolor_hsv.v = 255;
        ledcolor_hsv.s = 255;
      }


    }
    if (gravitycolor_active)
    {
      int tilting;
      if (abs(x) >= abs(y)) tilting = x;
      else tilting = y;
      tilting = tilting / 4;
      tilting = constrain(tilting, -15, 15); //limit x so no overflows happen below



      if (tilting > 10)
      {
        if (delaycounter > (15 - tilting))
        {
          delaycounter = 0;
          if (led_state == STATE_CHANGECOLOR)
          {
            ledcolor_hsv.h++;
          }
          if (led_state == STATE_CHANGEBRIGHTNES)
          {
            if (ledcolor_hsv.v < 254) //no overflow permitted!
              ledcolor_hsv.v += 2;
          }
          if (led_state == STATE_CHANGESATURATION)
          {
            if (ledcolor_hsv.s < 251
               ) //no overflow permitted!
              ledcolor_hsv.s += 5;
          }
        }
      }
      else if ( tilting < -10)
      {
        if (delaycounter > (15 + tilting))
        {
          delaycounter = 0;
          if (led_state == STATE_CHANGECOLOR)
          {
            ledcolor_hsv.h--;
          }
          if (led_state == STATE_CHANGEBRIGHTNES)
          {
            if (ledcolor_hsv.v > 90) //no overflow permitted, no low values permitted
              ledcolor_hsv.v -= 2;
          }
          if (led_state == STATE_CHANGESATURATION)
          {
            if (ledcolor_hsv.s > 30) //no overflow permitted, no zero permitted
              ledcolor_hsv.s -= 5;
          }
        }
      }
    }

    switch (ledmode)
    {
      case STATICMODE:
        staticUpdate();
        powerDown(WDTO_15MS);
        if (ontimeCounter % (44 * 60) == 0) //execuded about once every minute, normal mode runs at 44Hz
        {
          minutecounter++;
          checkVoltages(); //check battery voltage once per minute
        }
        break;
      case CANDLEMODE:
        candleUpdate(ledcolor_hsv.h); //candle with current led color as base hue
        delay(3);
        if (ontimeCounter % (300 * 60) == 0) //candle mode runs at about 300Hz
        {
          minutecounter++;
          checkVoltages(); //check battery voltage once per minute

        }
        break;
      //add other modes here
      default:
        staticUpdate();
        break;
    }



    delaycounter++;

    if (switchoffcounter > 50) //switch led off if turned upside down for some time
    {
      switchLEDoff(true);
      // LowPower.powerDown(SLEEP_4S, ADC_OFF, BOD_OFF); //sleep so the light can be set back down after flipping it upside down
      powerDown(WDTO_4S);
    }


    if (minutecounter > AUTOPOWEROFFTIME)
    {
      switchLEDoff(true);
    }

    if (voltageLow)
    {
      lowVoltageWarning(); //blink and shutdown
    }

  }


  /*****************************
     LOW POWER MODE STARTS HERE
   *****************************/

  else //low power mode, check accelerometer every 2 seconds
  {

#ifdef SERIALDEBUG
    delay(10); //wait for serial prints to finish
#endif
    wakeup = false; //reset wakeup variable
    if (voltageLow == false) //battery voltage is ok, check accelerometer
    {
      adxl_setup(); //startup the accelerometer
      ADXL_ISR(); //check accelerometer interrupts by polling
      wakeup = false;
      powerDown(WDTO_250MS);
      ADXL_ISR(); //check accelerometer interrupts by polling (sets wakeup if shaking is detected)
    }
    if (wakeup)
    {
      FastLED.setBrightness(getLongrunningBrightness(getBatteryVoltage()));
      //FastLED.setBrightness(BRIGHTNESS); //set default brightness
      switchLEDon(true);
      powerDown(WDTO_2S); //wait for accelerometer to calm down
      ADXL_ISR(); //clear interrupts
      led_state = STATE_CHANGECOLOR;
      tap_detect = false;
      doubletap_detect = false;
      autoOn = false; //this is a manual on

    }
    else //no wakup shaking detected, go back to sleep (or turn led on if it is getting dark outside)
    {
#ifdef SERIALDEBUG
      Serial.println("no wakeup signal");
      delay(50); //wait for serial prints to finish
      return;//do not go to sleep
#endif
      adxl_powerdown(); //set accelerometer power power and I2C pins low
      if (voltageLow)
      {
        powerDown(WDTO_8S);
      }
      else
      {
        powerDown(WDTO_1S);
      }

      lowPowerCheckCounter++;

      if (lowPowerCheckCounter > 60) //check about once every minute (or every 8 minutes if battery voltage is low)
      {

        lowPowerCheckCounter = 0;
        checkVoltages(); //check input voltages (and determine day and night time, switch on if dark for some time)
        if (voltageLow)
        {
          lowVoltageWarning(); //blink as a warning every 8 minutes if voltage is low
        }

      }
    }

  }
}

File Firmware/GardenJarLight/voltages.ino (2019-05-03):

/*************************
  SOLAR GARDEN JAR LIGHT

  by Damian Schneider
 *************************

   Copyright (c) Damian Schneider 2017

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
   You should have received a copy of the GNU General Public License along with
   this program. If not, see <http://www.gnu.org/licenses/>.
*/



/*
   Functions to monitor solar cell and battery voltages
   input voltage has a 11:1 voltage divider (10M and 1M resistor) and the internal reference voltage is 1.1V
*/
#define VOLTAGEATDAWN 700 //solar cell voltage threshold indicating it is now dark outside
#define VOLTAGEDAYLIGHT 3000 //solar cell voltage threshold to determine broad daylight
#define BATTERYMINVOLTAGE 3500 //battery voltage in mV when the auto-on at dawn will switch off 
#define BATTERYONVOLTAGE 3700 //battery voltage in mV that is (minimally) required to perform auto-switch on at dawn (set to same as BATTERYMINVOLTAGE to always switch on)
#define BATTERYCRITICALVOLTAGE 3400 //critical battery voltage in mV, below this, accelerometer is not checked anymore, low power interval is maximized (battery is almost empty if this dicharge voltage is reached)


//voltage in [mV]
unsigned int getBatteryVoltage(void)
{
  unsigned int adcValue = analogRead(BATTERYVOLTAGE_PIN);
#ifdef SERIALDEBUG
  unsigned int outvoltage = (unsigned int)(((long)adcValue * 1100 * 11) >> 10);
  Serial.print("battery voltage: ADC = ");
  Serial.print(adcValue);
  Serial.print(" mV = ");
  Serial.println(outvoltage);
#endif
  return (unsigned int)(((long)adcValue * 1100 * 11) >> 10);

}

//voltage in [mV]
unsigned int getSolarVoltage(void)
{
  unsigned int adcValue = analogRead(SOLARVOLTAGE_PIN);
#ifdef SERIALDEBUG
  unsigned int outvoltage = (unsigned int)(((long)adcValue * 1100 * 11) >> 10);
  Serial.print("solar voltage: ADC = ");
  Serial.print(adcValue);
  Serial.print("  mV =");
  Serial.println(outvoltage);
#endif
  return (unsigned int)(((long)adcValue * 1100 * 11) >> 10);
}

bool checkDarkness(void)
{
  if (getSolarVoltage() < (unsigned int)VOLTAGEATDAWN)
    return true;
  else
    return false;
}

bool checkBroadDaylight(void)
{
  if (getSolarVoltage() > (unsigned int)VOLTAGEDAYLIGHT)
    return true;
  else
    return false;
}

bool checkAutoOff(void)
{
  if (getBatteryVoltage() < BATTERYMINVOLTAGE)
    return true;
  else
    return false;
}

bool checkLowVoltage(void)
{
  static uint8_t lowvoltagecounter = 0; //used to detect low voltage multiple times to make sure it is not just a noise spike
  if (getBatteryVoltage() < BATTERYCRITICALVOLTAGE)
  {
    lowvoltagecounter++;
    if (lowvoltagecounter > 3)
    {
      lowvoltagecounter = 4;
      return true;
    }
    else
    {
      return false;
    }
  }
  else
  {
    lowvoltagecounter = 0;
    return false;
  }
}

//map the battery voltage to a brightness level so the light will stay on for the longest time depending on the juice left
uint8_t getLongrunningBrightness(unsigned int batVoltage)
{
   //calculate brightness from battery voltage: at 3.7V use minimum brightness, above 4.1V use high brightness (=AUTOMAXBRIGHTNESS)
        unsigned int brightnessvalue = map(batVoltage, BATTERYONVOLTAGE, 4250,AUTOMINBRIGHTNESS , AUTOMAXBRIGHTNESS);
        brightnessvalue = constrain(brightnessvalue, AUTOMINBRIGHTNESS,AUTOMAXBRIGHTNESS);  

        return (uint8_t)brightnessvalue;
}

//handle voltage checking, determine day and night time, execute about once per minute
void checkVoltages(void)
{

  //check if it's dark, switch on if it is

  //check if it's dark outside (check this once per minute)
  if (checkDarkness() && itsDarkOutside < 30) {
    itsDarkOutside++;
  }
  else if (itsDarkOutside > 0)
  {
    itsDarkOutside--;
  }

  //#ifdef SERIALDEBUG
  //  Serial.print("itsDarkOutside = ");
  //  Serial.println(itsDarkOutside);
  //#endif

  if (running == false) //only check auto-on if not already running
  {
    if (itsDarkOutside > 10) //check if dark for more than 10 minutes and not yet run
    {
      unsigned int currentBatteryVoltage = getBatteryVoltage();
      if (autoOn == false && (currentBatteryVoltage > BATTERYONVOLTAGE) )
      {
        autoOn = true; //automatically turned on the light       
        FastLED.setBrightness(getLongrunningBrightness(currentBatteryVoltage)); //set to lower brightness so the harnessed power lasts longer

#ifdef RANDOMCOLORATWAKEUP
        ledcolor_hsv.h = random(255); //turn on using random color
        ledcolor_hsv.s = 255;  //full color
        ledcolor_hsv.v = 255;  //full brightness (still limited by global 'setBrightness' value)
        ledmode = CANDLEMODE;
#endif
        switchLEDon(true);
        adxl_setup(); //startup the accelerometer
        //clear interrupts
        ADXL_ISR();
        tap_detect = false;
        doubletap_detect = false;
      }
    }
    else if (itsDarkOutside < 5) //daylight
    {
      autoOn = false; //reset for next time it gets dark
    }
  }
  else //light is running, check if it is bright daylight outside, switch off if it is
  {
    if (checkBroadDaylight())
    {
      switchLEDoff(true); //fadeout and shut down
    }

  }

  if (checkLowVoltage())
  {
    voltageLow = true;
  }
  else
  {
    voltageLow = false;
  }

  if (checkAutoOff() && autoOn && voltageLow == false) //check for minimum auto-mode battery voltage (only switch off if voltage is not low, let the main show the warning, then switch off)
  {
    switchLEDoff(true); //fadeout and shut down
  }

}

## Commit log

2017-07-11 Auto switchoff bugfix
    automatic switchoff happened way too soon, found a bug in the time
    calculation
    [GardenJarLight.ino, LowPower.ino, accelerometer.ino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]
2017-07-11 fixed bug in timing
    [GardenJarLight.ino, voltages.ino]
2017-07-12 more timing bugfixes & adjustments
    [GardenJarLight.ino, voltages.ino]
2017-07-15 small update
    added brightness and saturation reset upon double tap, changed auto-off
    time to 5 hours
    [GardenJarLight.ino, voltages.ino]
2017-07-20 BUGFIX: auto-on works now
    auto on worked only once, the minutecounter was not reset. also adjusted
    some constants
    [GardenJarLight.ino, LowPower.ino, led_stuff.ino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]
2017-07-23 increased watchtdog timeout
    bootloader kept resetting at 250ms
    [GardenJarLight.ino, LowPower.ino, voltages.ino]
2017-07-29 updated schematic
2017-08-01 Diverse Schreibfehler behoben, BOM aktualisiert
2017-08-01 bauanleitung update, bom und typos
2017-08-01 updated silkscreen
    [GardenJarLight_V1.brd, GardenJarLight_V1.sch]
2017-08-05 bugfix & added daytime shutdown
    fixed a bug where after double tap it does not go to color changing mode
    but to brightness chaning mode.
    Added a feature: during broad daylight it shuts down automatically after
    one minute or so
    [voltages.ino]
2017-09-10 added auto off during daylight
    and some bugfixes
    [GardenJarLight.ino, LowPower.ino, led_stuff.ino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]
2017-11-15 watchdog bug fixed
    (probably) found and fixed the bug where the watchdog was able to reset
    the system twice in a row, causing the bootloader to get stuck in an
    infinite loop.
    [GardenJarLight.ino, LowPower.ino, voltages.ino]
2019-01-07 some tweaking or parameters and bugfixes
    [GardenJarLight.ino, LowPower.ino, accelerometer.ino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]
2019-05-03 Added color randomisation and auto adjusting brightness
    also did some more testing, found a correctly working version for
    infinite loops
    also upon auto-on the color is chosen randomly
    the brightness is chosen according to power left in the battery, if
    battery did not charge much, brightness is reduced so lanterns should
    turn on most days even in the winter.
    [GardenJarLight.ino, LowPower.ino, voltages.ino]

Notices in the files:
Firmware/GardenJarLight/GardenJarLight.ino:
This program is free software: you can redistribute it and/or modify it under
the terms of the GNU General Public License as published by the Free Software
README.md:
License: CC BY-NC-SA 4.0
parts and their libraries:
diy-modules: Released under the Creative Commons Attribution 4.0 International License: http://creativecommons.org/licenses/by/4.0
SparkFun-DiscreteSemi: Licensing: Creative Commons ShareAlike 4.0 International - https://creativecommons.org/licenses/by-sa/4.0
